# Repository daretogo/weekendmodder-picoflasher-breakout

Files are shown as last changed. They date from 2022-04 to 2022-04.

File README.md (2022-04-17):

# weekendmodder-picoflasher-breakout
Repo to home open source files for the PicoFlasher breakout board made with  [@ShawMerlin](https://github.com/ShawMerlin?tab=repositories)

Code for this project is located - https://github.com/X360Tools/PicoFlasher

This board is currently in prototyping phase.  More details to come.

V1.4 has been created and fixes the colors pinouts to match JST Cable color cables.





GNU General Public License v3.0  (Free for use)

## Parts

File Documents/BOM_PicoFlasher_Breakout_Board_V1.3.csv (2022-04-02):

Comment | Designator | Footprint | LCSC
Debug Red | D1 | LED_0805_2012Metric_Pad1.15x1.40mm_HandSolder | C84256
eMMC LED Orange | D2 | LED_0805_2012Metric_Pad1.15x1.40mm_HandSolder | C84262
SPI LED Blue | D3 | LED_0805_2012Metric_Pad1.15x1.40mm_HandSolder | C2293
Power LED Green | D4 | LED_0805_2012Metric_Pad1.15x1.40mm_HandSolder | C2297
1k 1206 - 4x0603 Resistor Array | RN1 | R_Array_Convex_4x0603 | C20197
9P 1.5mm SMD Board to Wire | J1 | CONN-SMD_HX15001-9AWB | C442156
7P 1.5mm SMD Board to Wire | J2 | CONN-SMD_HX15001-7AWB | C442154
5P 1.5mm SMD Board to Wire | J3 | CONN-SMD_HX15001-5AWB | C442152

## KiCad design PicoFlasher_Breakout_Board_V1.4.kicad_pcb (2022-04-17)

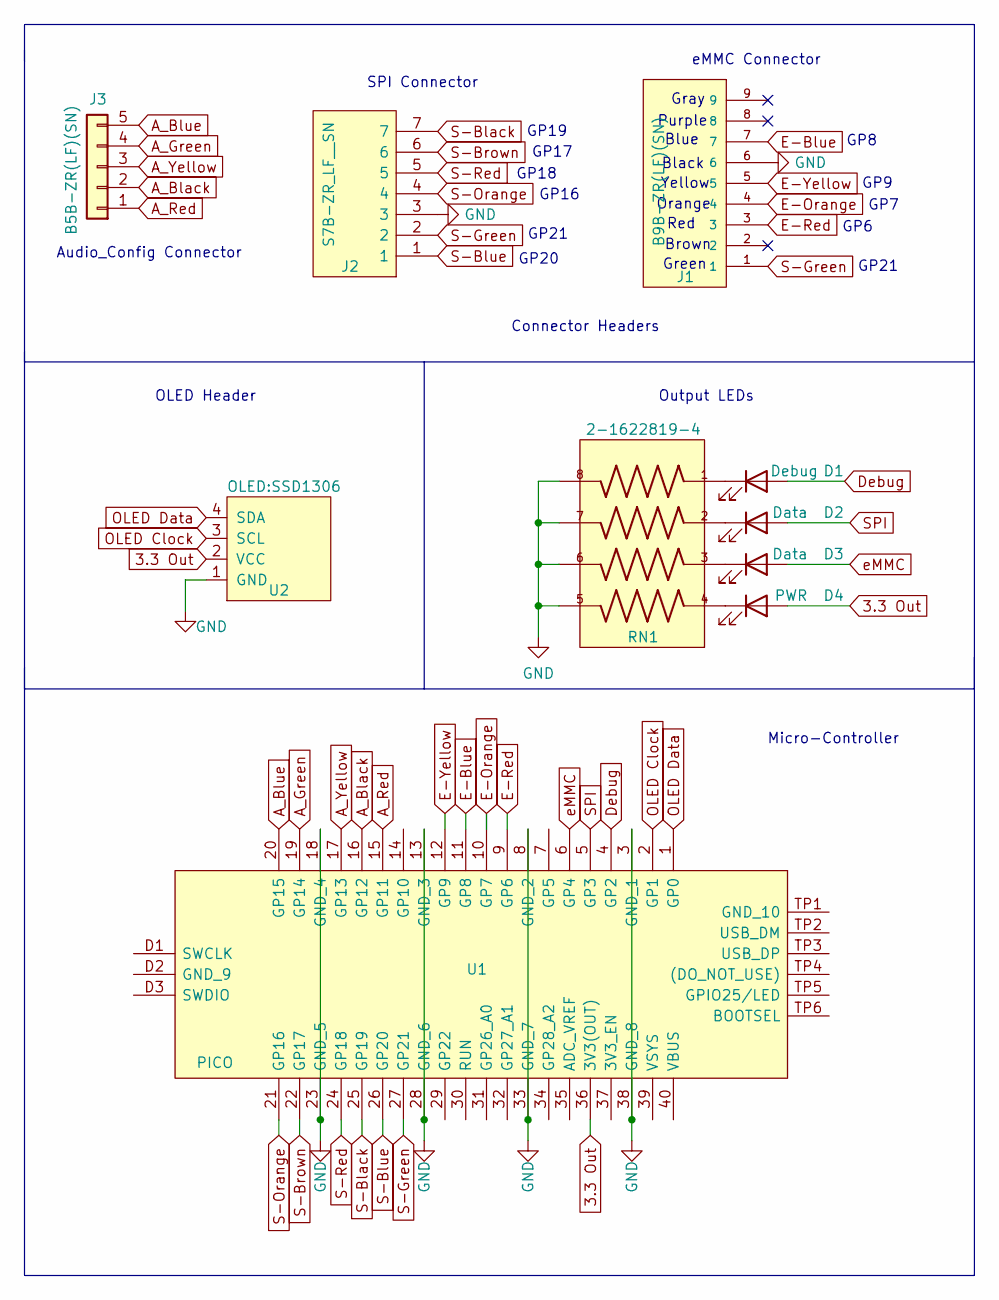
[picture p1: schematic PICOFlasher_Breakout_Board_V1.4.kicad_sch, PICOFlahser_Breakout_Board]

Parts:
D1: Debug; LED_0805_2012Metric_Pad1.15x1.40mm_HandSolder
D2, D3: Data; LED_0805_2012Metric_Pad1.15x1.40mm_HandSolder
D4: PWR; LED_0805_2012Metric_Pad1.15x1.40mm_HandSolder
J1: B9B-ZR(LF)(SN); JST_B9B-ZR(LF)(SN)
J2: S7B-ZR_LF__SN; S7BZRLFSN; Manufacturer_Part_Number S7B-ZR(LF)(SN)
J3: B5B-ZR(LF)(SN); JST_B5B-ZR(LF)(SN)
RN1: 2-1622819-4; R_Array_Convex_4x0603
U1: PICO; PICO_THT; Manufacturer_Part_Number PICO
U2: OLED:SSD1306; 128x64OLED

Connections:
3.3 Out: D4.2 (A), U1.36 (3V3(OUT)), U2.2 (VCC); also elsewhere on the board
A_Black: J3.2, U1.16 (GP12); also elsewhere on the board
A_Blue: J3.5, U1.20 (GP15); also elsewhere on the board
A_Green: J3.4, U1.19 (GP14); also elsewhere on the board
A_Red: J3.1, U1.15 (GP11); also elsewhere on the board
A_Yellow: J3.3, U1.17 (GP13); also elsewhere on the board
Debug: D1.2 (A), U1.4 (GP2); also elsewhere on the board
E-Blue: J1.7, U1.11 (GP8); also elsewhere on the board
E-Orange: J1.4, U1.10 (GP7); also elsewhere on the board
E-Red: J1.3, U1.9 (GP6); also elsewhere on the board
E-Yellow: J1.5, U1.12 (GP9); also elsewhere on the board
GND: J1.6, J2.3, RN1.5, RN1.6, RN1.7, RN1.8, U1.3 (GND_1), U1.8 (GND_2), U1.13 (GND_3), U1.18 (GND_4), U1.23 (GND_5), U1.28 (GND_6), U1.33 (GND_7), U1.38 (GND_8), U2.1 (GND); also elsewhere on the board
unnamed: D1.1 (K), RN1.1
unnamed: D2.1 (K), RN1.2
unnamed: D3.1 (K), RN1.3
unnamed: D4.1 (K), RN1.4
OLED Clock: U1.2 (GP1), U2.3 (SCL); also elsewhere on the board
OLED Data: U1.1 (GP0), U2.4 (SDA); also elsewhere on the board
S-Black: J2.7, U1.25 (GP19); also elsewhere on the board
S-Blue: J2.1, U1.26 (GP20); also elsewhere on the board
S-Brown: J2.6, U1.22 (GP17); also elsewhere on the board
S-Green: J1.1, J2.2, U1.27 (GP21)
S-Orange: J2.4, U1.21 (GP16); also elsewhere on the board
S-Red: J2.5, U1.24 (GP18); also elsewhere on the board
SPI: D2.2 (A), U1.5 (GP3); also elsewhere on the board
eMMC: D3.2 (A), U1.6 (GP4); also elsewhere on the board

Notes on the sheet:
Yellow
Brown
GP16
GP21
GP17
Gray
Micro-Controller
GP8
Red
Audio_Config Connector
Connector Headers
Black
OLED Header
Output LEDs
GP20
GP18
GP7
Blue
Green
Purple
eMMC Connector
Orange
GP19
GP9
SPI Connector
GP6

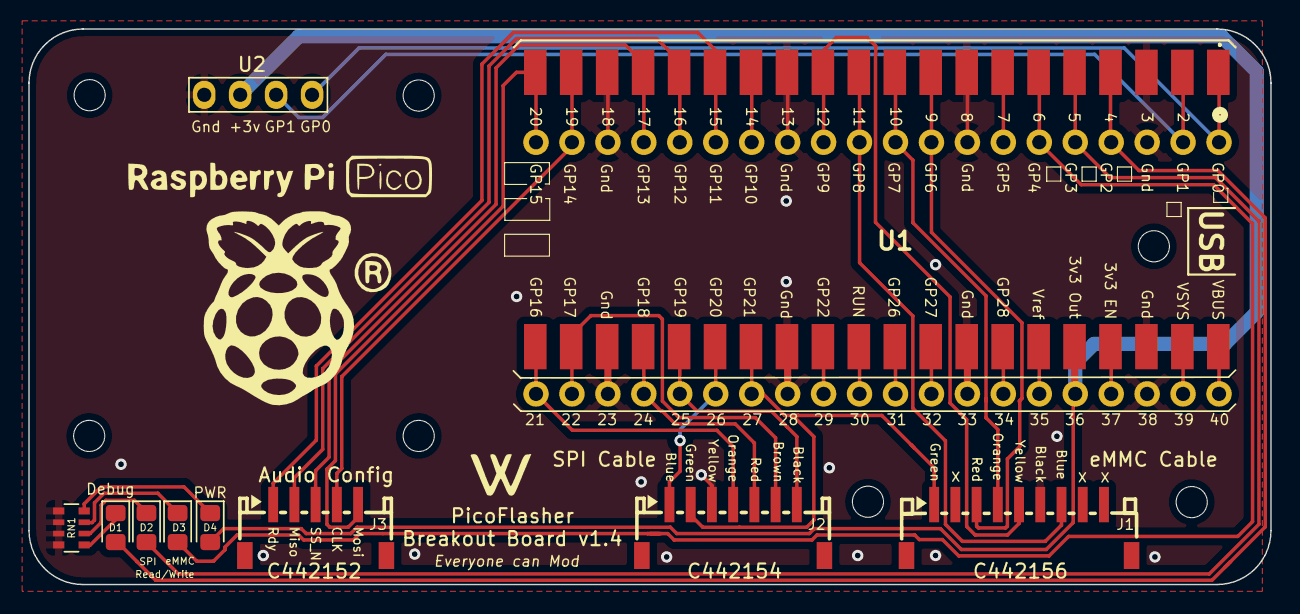
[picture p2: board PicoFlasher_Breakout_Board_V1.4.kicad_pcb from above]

Board: 2 copper layers, 87.8 x 39.2 mm, 11 parts (0 on the bottom side), 26 nets.

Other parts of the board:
U1e: PICO; PICO_SMD

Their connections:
3.3 Out: U1e.36 (3V3(OUT)); also elsewhere on the board
A_Black: U1e.16 (GP12); also elsewhere on the board
A_Blue: U1e.20 (GP15); also elsewhere on the board
A_Green: U1e.19 (GP14); also elsewhere on the board
A_Red: U1e.15 (GP11); also elsewhere on the board
A_Yellow: U1e.17 (GP13); also elsewhere on the board
Debug: U1e.4 (GP2); also elsewhere on the board
E-Blue: U1e.11 (GP8); also elsewhere on the board
E-Orange: U1e.10 (GP7); also elsewhere on the board
E-Red: U1e.9 (GP6); also elsewhere on the board
E-Yellow: U1e.12 (GP9); also elsewhere on the board
GND: U1e.3 (GND_1), U1e.8 (GND_2), U1e.13 (GND_3), U1e.18 (GND_4), U1e.23 (GND_5), U1e.28 (GND_6), U1e.33 (GND_7), U1e.38 (GND_8); also elsewhere on the board
OLED Clock: U1e.2 (GP1); also elsewhere on the board
OLED Data: U1e.1 (GP0); also elsewhere on the board
S-Black: U1e.25 (GP19); also elsewhere on the board
S-Blue: U1e.26 (GP20); also elsewhere on the board
S-Brown: U1e.22 (GP17); also elsewhere on the board
S-Orange: U1e.21 (GP16); also elsewhere on the board
S-Red: U1e.24 (GP18); also elsewhere on the board
SPI: U1e.5 (GP3); also elsewhere on the board
eMMC: U1e.6 (GP4); also elsewhere on the board
